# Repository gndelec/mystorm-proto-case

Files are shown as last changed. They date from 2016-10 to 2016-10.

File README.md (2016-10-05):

# myStorm Open Case and Prototyping Kit

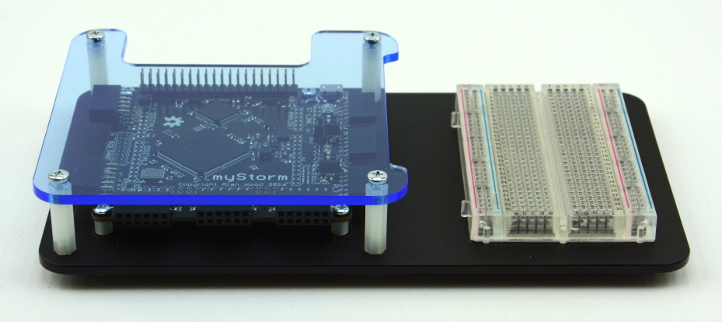
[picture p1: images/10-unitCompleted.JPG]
A myStorm board fitted in a MYSC-01 case


The [MYSC-01 kit](http://abopen.com/MYSC-01) is a simple but elegant case based on the "[sick of beige](http://dangerousprototypes.com/docs/Sick_of_Beige_basic_case_v1)" design to aid with breadboard prototyping and work with the myStorm FPGA board. It can be bought from [Ground Electronics](http://groundelectronics.com).

## Repository contents

The case design is provided in the following formats:

* Inkscape SVG (source)
* PDF
* DXF

The top and bottom panels are laser cut from 3mm acrylic.

## Bill of materials

In addition to the acrylic parts the MYSC-01 kit contains:

| Qty | Item |
| --- | --- |
|  4  | M2.5 12mm steel machine screw |
|  4  | M2.5 steel hex nut |
|  4  | M3 5mm nylon circular spacer |
|  4  | M3 20mm nylon hex FF standoff |
|  8  | M3 8mm steel machine screw |
|  1  | Self adhesive 400-point breadboard  |
|  6  | Self adhesive rubber foot/bumper |

## Assembly

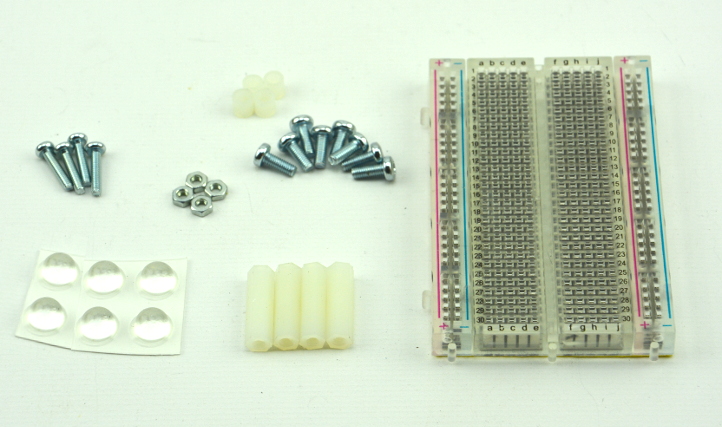
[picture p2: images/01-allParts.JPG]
All parts


1. Layout all parts
2. Peel off acrylic backing, ensuring any static charge discharged before handling myStorm board.
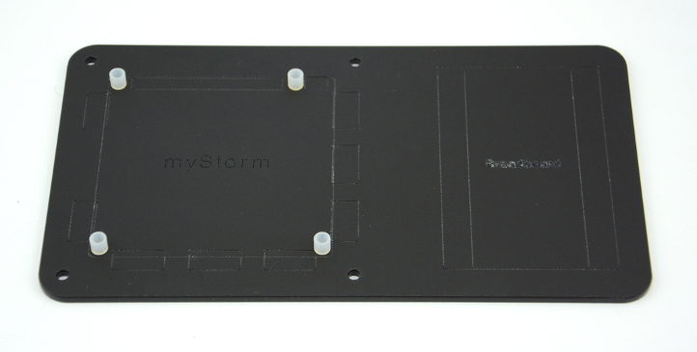
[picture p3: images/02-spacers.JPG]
Spacers on baseplate

3. Position 4 x M3x5mm nylon spacers over myStorm mounting holes.
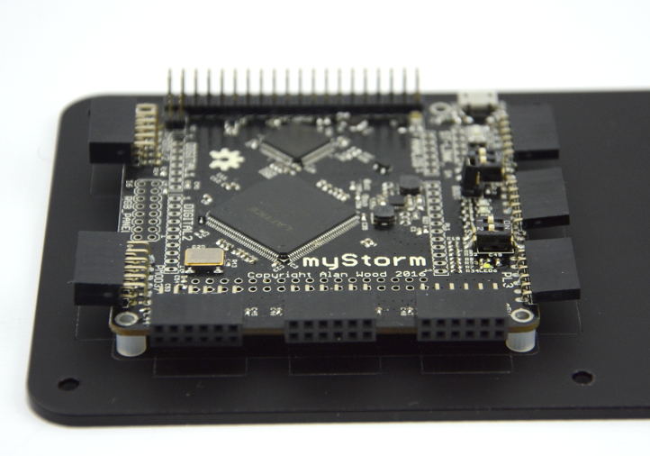
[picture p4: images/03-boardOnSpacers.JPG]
myStorm on spacers

4. Position myStorm board on top of spacers, paying attention to the base plate indicating correct orientation.
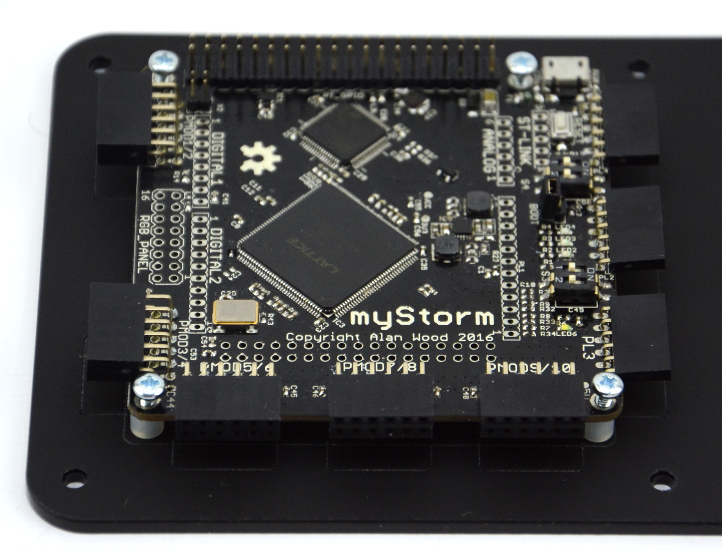
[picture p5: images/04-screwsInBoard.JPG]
Adding screws

5. Add 4 x M2.5x12mm machine screws through myStorm board, spacers and base plate. Pay extra attention + take care when adding screw near to component C44, as it is -very- close to the mounting hole.
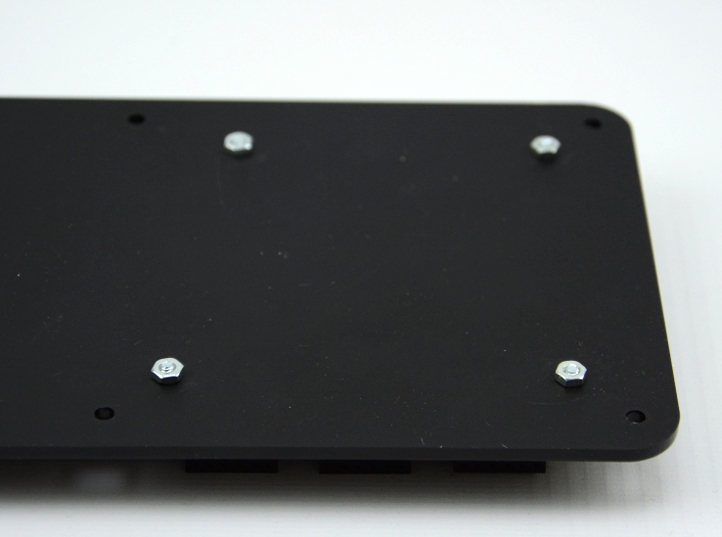
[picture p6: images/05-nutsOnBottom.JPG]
Adding nuts

6. Carefully lift all and add 4 x M2.5 hex nuts to screws.
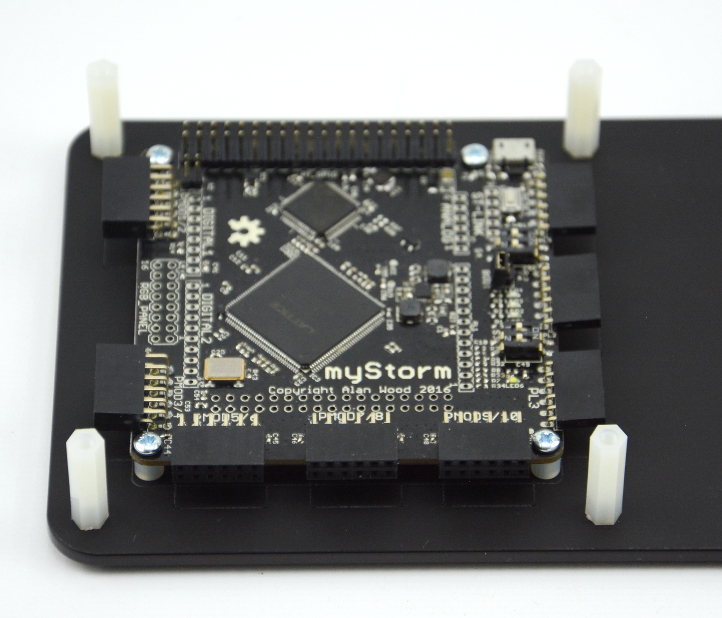
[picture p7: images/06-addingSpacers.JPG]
Adding standoffs

7. Use 4 x M3x8mm machine screws to mount 4 x M3x20mm nylon standoffs to the baseplate.
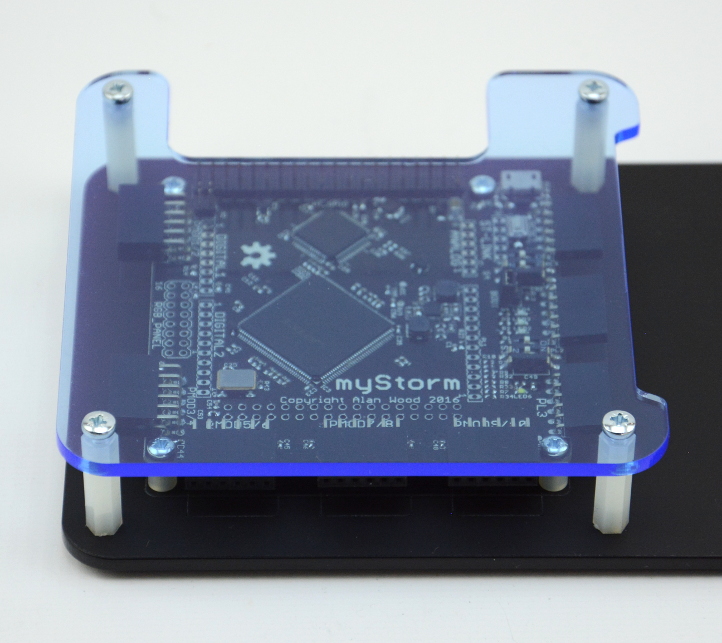
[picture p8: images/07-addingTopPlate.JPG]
Adding top plate

8. Position top plate on standoffs and use the remaining M3x8mm machine screws to secure in place, paying attention to the cut-outs and correct orientation.
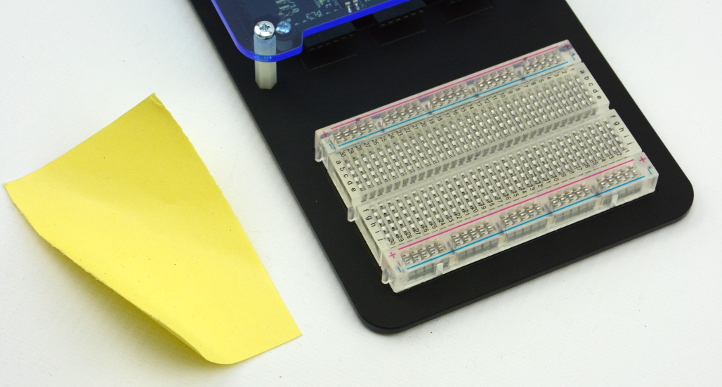
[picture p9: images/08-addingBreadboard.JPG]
Adding breadboard

9. Peel backing from breadboard and stick to the baseplate.
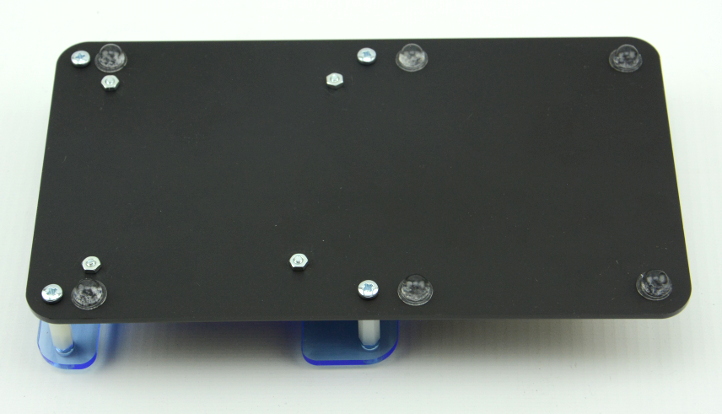
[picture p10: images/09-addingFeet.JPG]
Adding feet

10. Add self-adhesive rubber feet to base.
Unit complete
11. Unit is complete and ready to use!

## Changelog

| Version | Date | Summary |
|---|---|---|
| 1.0 | 05/10/16 | Initial version. |

## Licence

myStorm Open Prototyping Case Kit copyright 2016 [AB Open Ltd](http://abopen.com).

<br />This work is licensed under a <a rel="license" href="http://creativecommons.org/licenses/by/4.0/">Creative Commons Attribution 4.0 International License</a>.

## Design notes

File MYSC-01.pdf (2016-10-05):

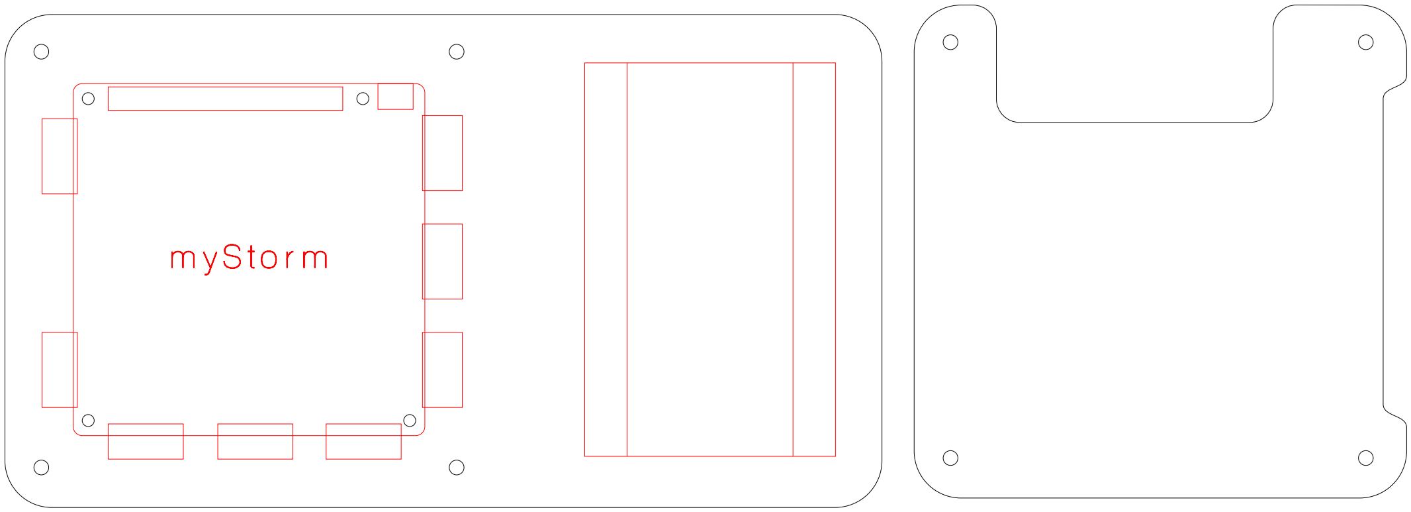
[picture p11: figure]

scale: square = 10mm
key:
red = vector etch
black = cut

recommended stock = 3mm acrylic sheet

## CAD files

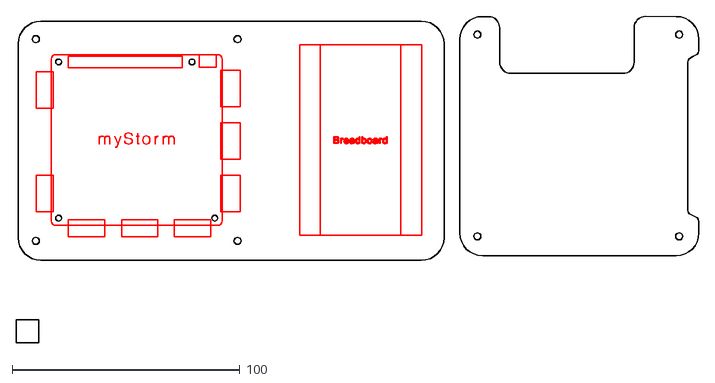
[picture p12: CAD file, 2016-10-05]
MYSC-01.dxf
299.8 x 143.2

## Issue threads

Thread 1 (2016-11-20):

move NE corner mount hole E by 10mm

drom, 2016-11-20:
@gndelec @monsonite I am mounting new revision of myStorm board into case that NE mount hole has moved to the corner. My guess that next revision of the case should accommodate this change?
